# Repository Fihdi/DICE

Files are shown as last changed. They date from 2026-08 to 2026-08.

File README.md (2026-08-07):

# 6hp Sample and Hold / Random voltage generator

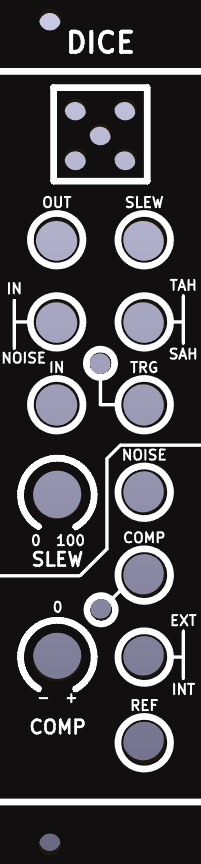
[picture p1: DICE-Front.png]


DICE contains a white noise generator, sample and hold and a comparator. This 6hp module creates various random voltages and gates, bringing variety and unpredictability into your patches. 

# Applications

- Random voltage generator
- Random gate generator
- Slew rate limiter
- Track and hold
- White noise generator
- Burst generator

# Jumpers
Two jumpers on the back of the module allow the COMP output to be configured:
- **Jumper in the ON position:** A trigger from TRG is always routed to the COMP output. This ensures an on-time trigger when using the COMP output as a burst generator.
- **Jumper in the OFF position**: The trigger from TRG is not routed to the COMP output.
- **Jumper in the AND position:** The COMP output is only active while a gate signal is present at the TRG input.
- **Jumper not in the AND position:** COMP outputs HIGH or LOW signals regardless of the TRG input.

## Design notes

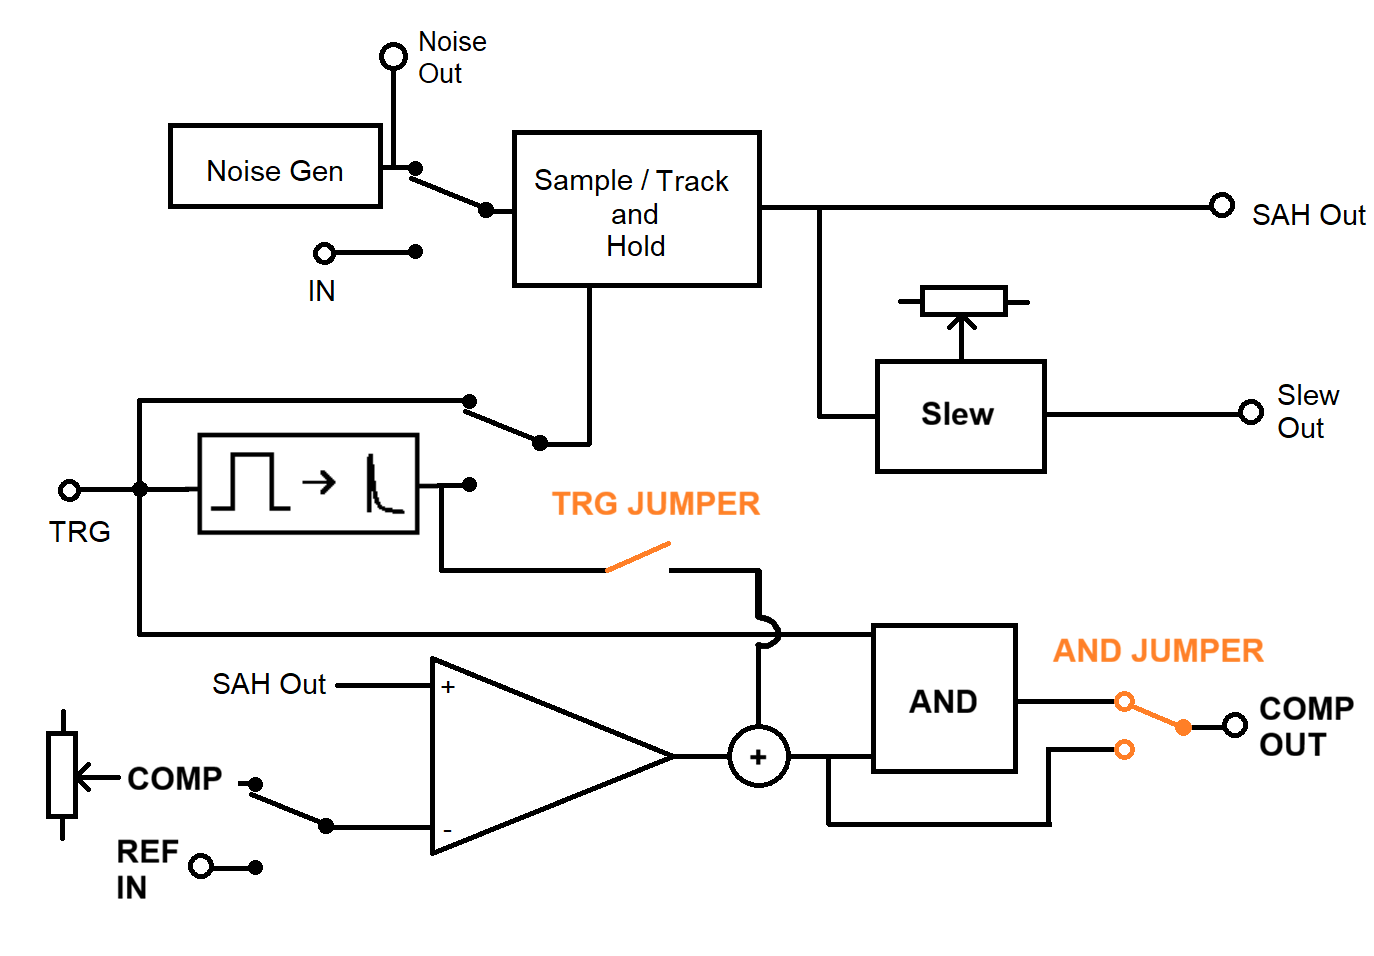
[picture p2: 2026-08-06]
DICE-BLOCK.png

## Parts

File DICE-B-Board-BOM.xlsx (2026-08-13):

 |  |  | DICE B-Board BOM
Item # | *Designator | *Qty | Manufacturer | *Mfg Part # | Description / Value | *Package/Footprint | Type | Your Instructions / Notes
1 | C1,C105,C106 | 3 |  | C309030 | 100n | Capacitor_SMD:C_1206_3216Metric
2 | C2 | 1 |  |  | 10p | Capacitor_SMD:C_1206_3216Metric |  | DNP
3 | C3,C104 | 2 |  | C377070 | 1u | Capacitor_SMD:C_1206_3216Metric
4 | C101,C103 | 2 |  | C5137623 | 10n | Capacitor_SMD:C_1206_3216Metric
5 | C102 | 1 |  | C282811 | 1n | Capacitor_SMD:C_1206_3216Metric
6 | D101,D102,D103,D104,D110,D111,D112,D113,D114,D117 | 10 |  | C917117 | 1N4148 | Diode_SMD:D_SOD-323_HandSoldering
7 | J2,J101,J109,J116 | 4 |  |  | Conn_01x03_Pin | Connector_PinHeader_2.54mm:PinHeader_1x03_P2.54mm_Vertical |  | DNP
8 | J110 | 1 |  |  | Conn_01x05_Pin | Connector_PinHeader_2.54mm:PinHeader_1x05_P2.54mm_Vertical |  | DNP
9 | J114,J115 | 2 |  |  | Conn_01x07_Pin | Connector_PinHeader_2.54mm:PinHeader_1x07_P2.54mm_Vertical |  | DNP
10 | Q101,Q102,Q103 | 3 |  | C475630 | BC847 | Package_TO_SOT_SMD:SOT-23
11 | R1,R134 | 2 |  | C2907373 | 1M | Resistor_SMD:R_1206_3216Metric
12 | R2 | 1 |  | C2090939 | 2M2 | Resistor_SMD:R_1206_3216Metric
13 | R4,R127,R128,R129,R130,R131 | 6 |  | C2907387 | 4k7 | Resistor_SMD:R_1206_3216Metric
14 | R5,R6,R13,R101,R102,R103,R104,R105,R106,R107,R108,R110,R111,R112,R114 | 15 |  | C2907421 | 100k | Resistor_SMD:R_1206_3216Metric
15 | R7,R113,R116 | 3 |  | C131398 | 1k | Resistor_SMD:R_1206_3216Metric
16 | R109,R123,R124,R125,R126 | 5 |  | C2907423 | 10k | Resistor_SMD:R_1206_3216Metric
17 | R119 | 1 |  | C2907507 | 47k | Resistor_SMD:R_1206_3216Metric
18 | R121,R122 | 2 |  | C2907483 | 33k | Resistor_SMD:R_1206_3216Metric
19 | U1,U102,U103 | 3 |  | C12594 | TL074 | Package_SO:SOIC-14_3.9x8.7mm_P1.27mm
20 | U101 | 1 |  | C6601631 | DG412xUE | Package_SO:TSSOP-16_4.4x5mm_P0.65mm

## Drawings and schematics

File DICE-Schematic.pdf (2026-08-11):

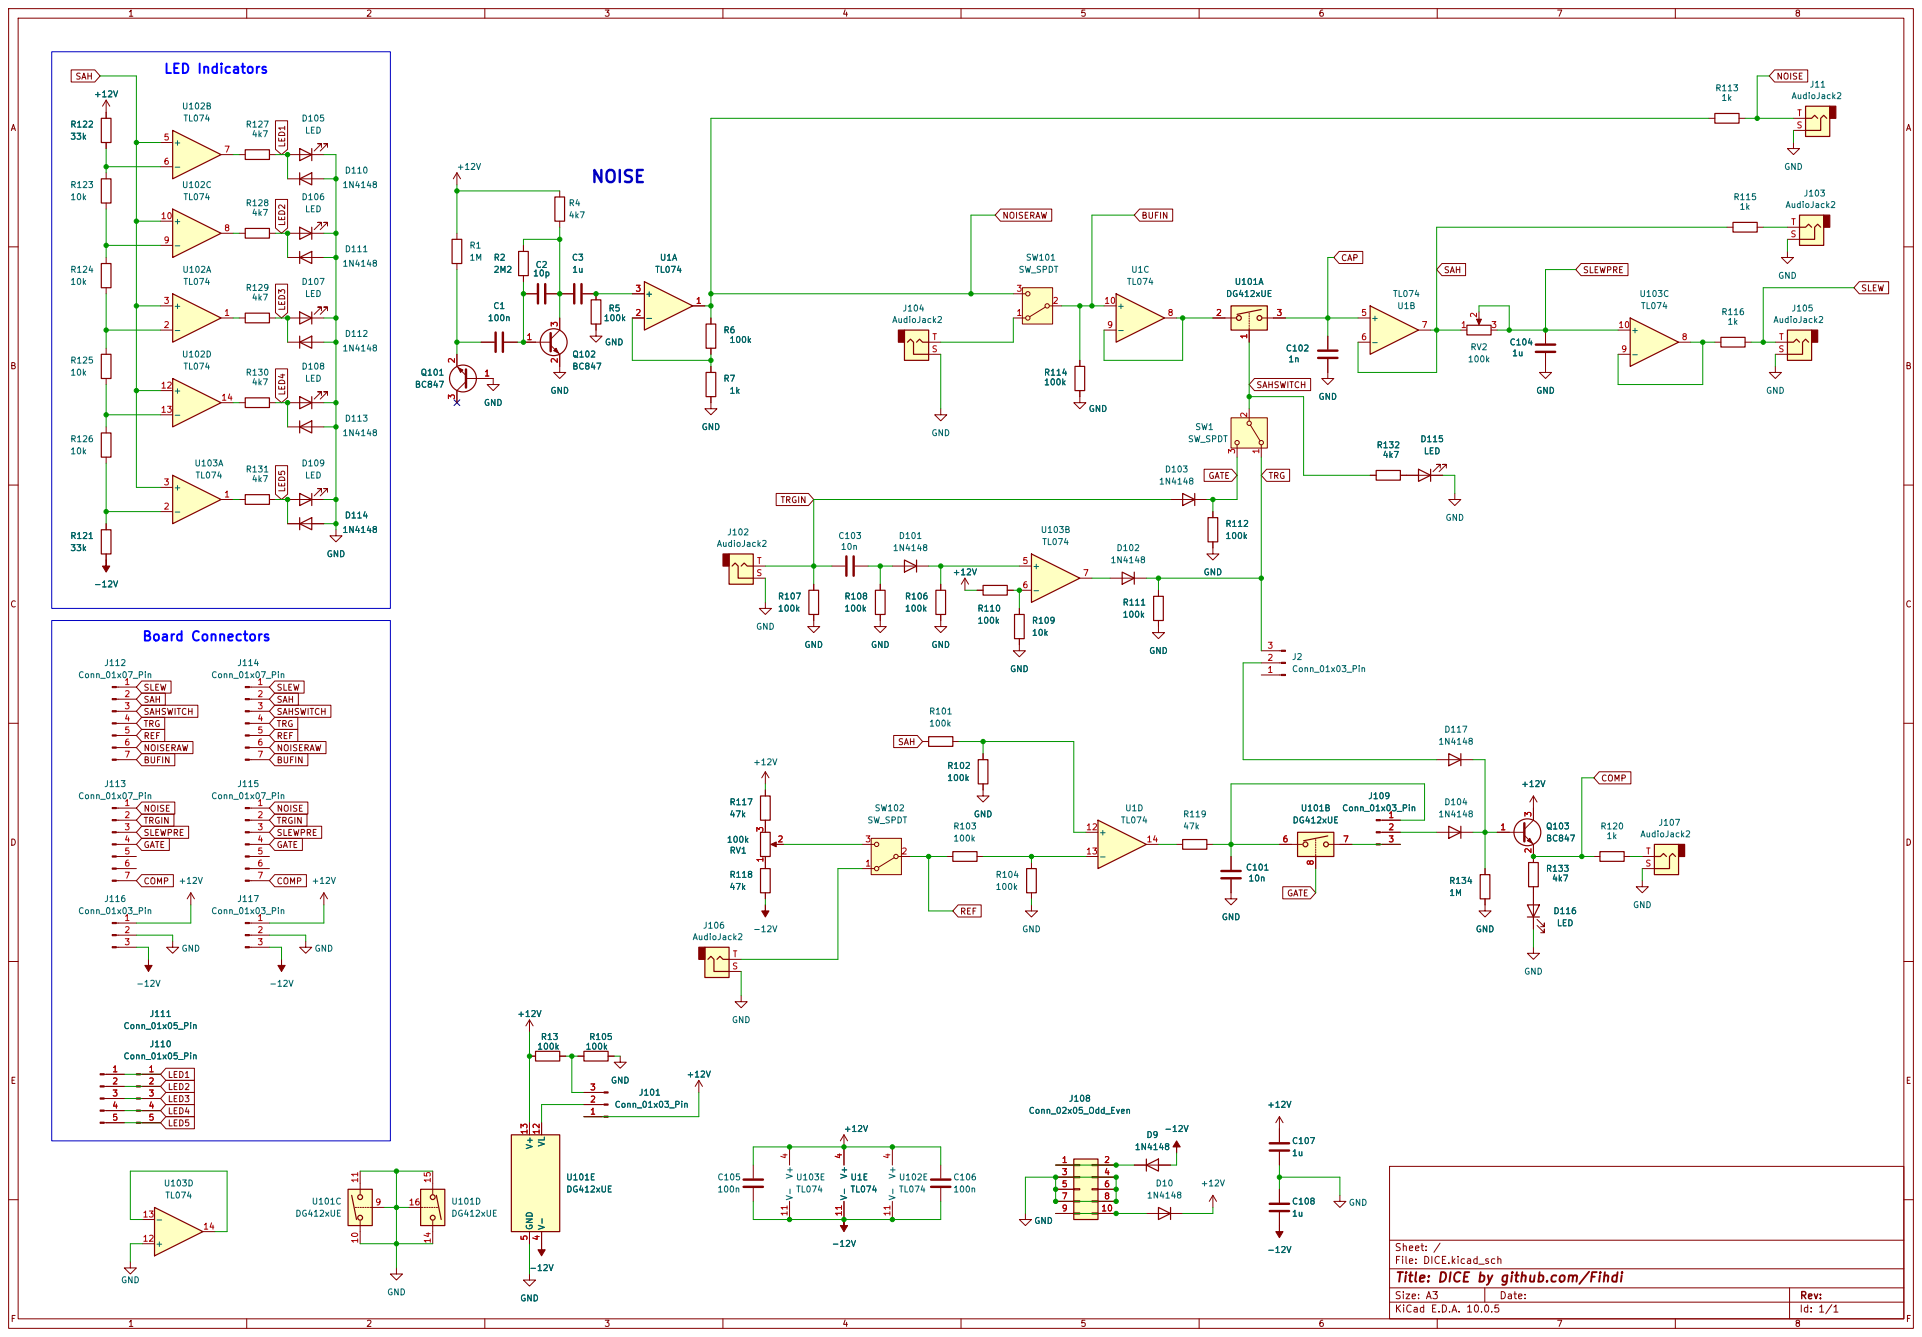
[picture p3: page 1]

Sheet: /
File: DICE.kicad_sch
Title: DICE by github.com/Fihdi

Size: A3 | Rev: | F Date:
KiCad E.D.A. 10.0.5 | Id: 1/1

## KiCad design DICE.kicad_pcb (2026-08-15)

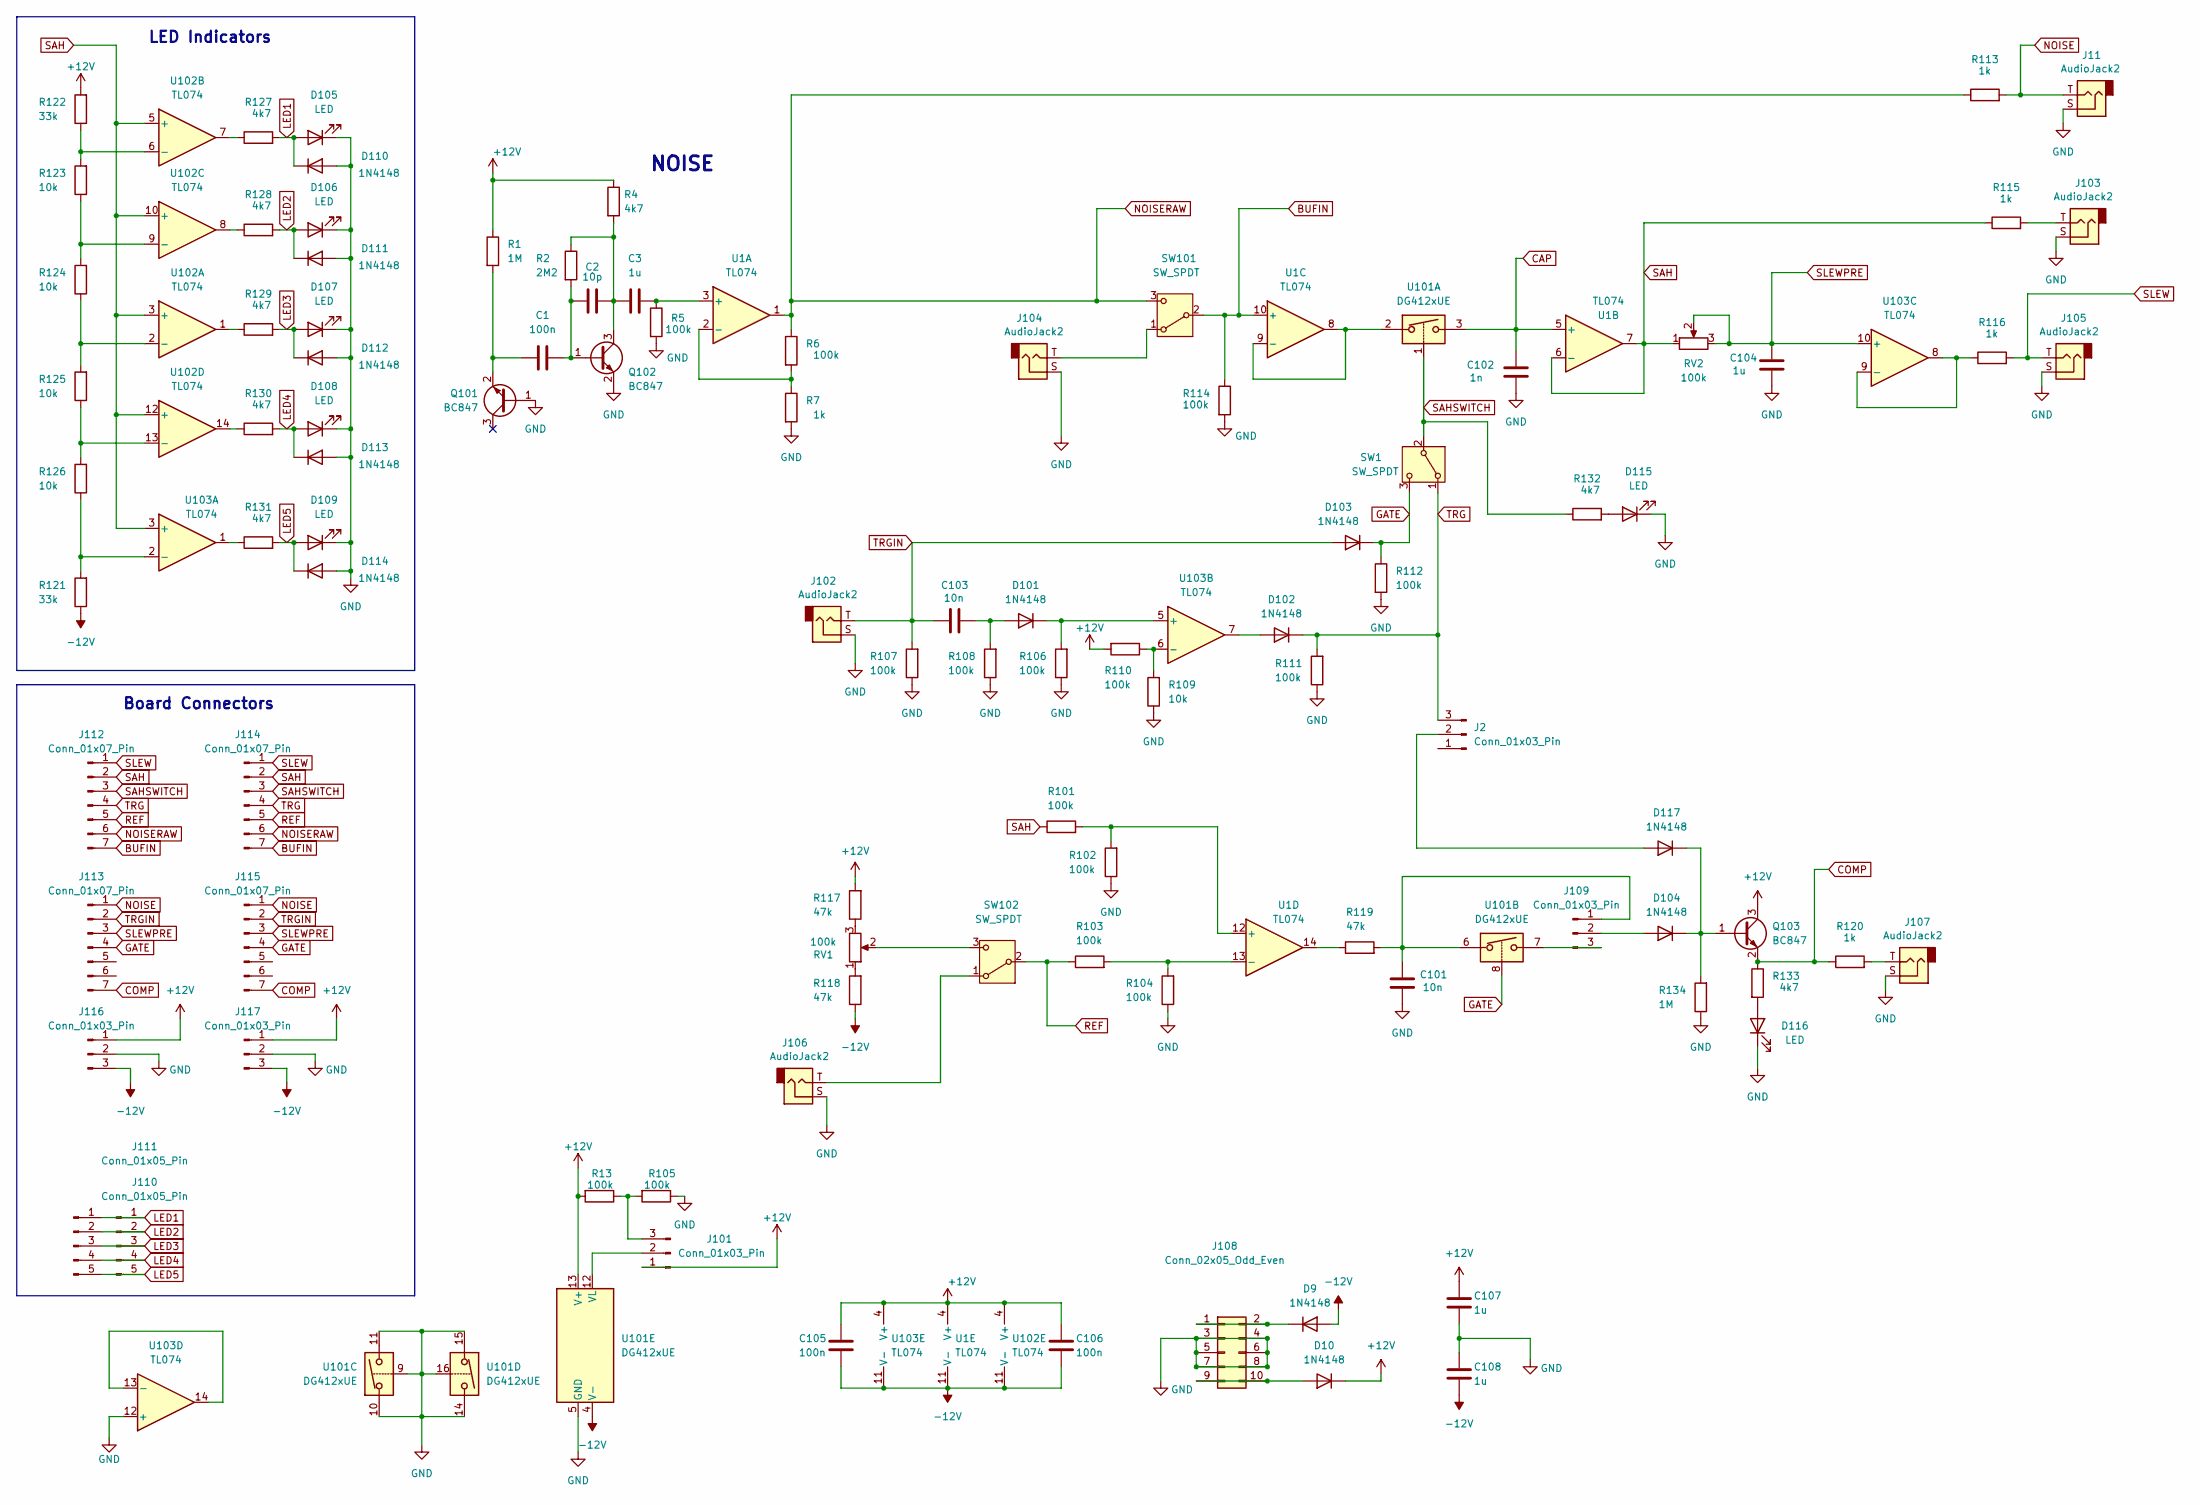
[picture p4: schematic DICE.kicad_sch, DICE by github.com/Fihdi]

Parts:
C1, C105, C106: 100n; C_1206_3216Metric
C2: 10p; C_1206_3216Metric
C3, C104, C107, C108: 1u; C_1206_3216Metric
C101, C103: 10n; C_1206_3216Metric
C102: 1n; C_1206_3216Metric
D9, D10, D101, D102, D103, D104, D110, D111, D112, D113, D114, D117: 1N4148; D_SOD-323_HandSoldering
D105, D106, D107, D108, D109, D115, D116: LED; LED_D3.0mm
J2, J101, J109, J116, J117: Conn_01x03_Pin; PinHeader_1x03_P2.54mm_Vertical
J11, J102, J103, J104, J105, J106, J107: AudioJack2; MonoTRS
J108: Conn_02x05_Odd_Even; IDC-Header_2x05_P2.54mm_Vertical
J110, J111: Conn_01x05_Pin; PinHeader_1x05_P2.54mm_Vertical
J112, J113, J114, J115: Conn_01x07_Pin; PinHeader_1x07_P2.54mm_Vertical
Q101, Q102, Q103: BC847; SOT-23
R1, R134: 1M; R_1206_3216Metric
R2: 2M2; R_1206_3216Metric
R4, R127, R128, R129, R130, R131, R132, R133: 4k7; R_1206_3216Metric
R5, R6, R13, R101, R102, R103, R104, R105, R106, R107, R108, R110, R111, R112, R114: 100k; R_1206_3216Metric
R7, R113, R115, R116, R120: 1k; R_1206_3216Metric
R109, R123, R124, R125, R126: 10k; R_1206_3216Metric
R117, R118, R119: 47k; R_1206_3216Metric
R121, R122: 33k; R_1206_3216Metric
RV1, RV2: 100k; Potentiometer_Alpha_RD901F-40-00D_Single_Vertical
SW1, SW101, SW102: SW_SPDT; Switch
U1, U102, U103: TL074; SOIC-14_3.9x8.7mm_P1.27mm
U101: DG412xUE; TSSOP-16_4.4x5mm_P0.65mm

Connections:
+12V: C105.1, C106.2, C107.2, D10.1 (K), J101.1, J116.1, J117.1, Q103.3 (C), R1.1, R4.1, R13.2, R110.2, R117.2, R122.2, U1.4 (V+), U101.13 (V+), U102.4 (V+), U103.4 (V+)
-12V: C105.2, C106.1, C108.1, D9.2 (A), J116.3, J117.3, R118.1, R121.1, U1.11 (V-), U101.4 (V-), U102.11 (V-), U103.11 (V-)
BUFIN: J112.7, J114.7, R114.1, SW101.2 (B), U1.10 (+)
CAP: C102.2, U1.5 (+), U101.3
COMP: J113.7, J115.7, Q103.2 (E), R120.1, R133.1
GATE: D103.1 (K), J113.4, J115.4, R112.1, SW1.3 (C), U101.8
GND: C101.1, C102.1, C104.1, C107.1, C108.2, D105.1 (K), D106.1 (K), D107.1 (K), D108.1 (K), D109.1 (K), D110.2 (A), D111.2 (A), D112.2 (A), D113.2 (A), D114.2 (A), D115.1 (K), D116.1 (K), J11.S, J102.S, J103.S, J104.S, J105.S, J106.S, J107.S, J108.3, J108.4, J108.5, J108.6, J108.7, J108.8, J116.2, J117.2, Q101.1 (B), Q102.2 (E), R5.2, R7.2, R102.1, R104.1, R105.1, R106.1, R107.1, R108.1, R109.1, R111.1, R112.2, R114.2, R134.1, U101.5 (GND), U101.9, U101.10, U101.11, U101.14, U101.15, U101.16, U103.12 (+)
LED1: D105.2 (A), D110.1 (K), J110.1, J111.1, R127.2
LED2: D106.2 (A), D111.1 (K), J110.2, J111.2, R128.2
LED3: D107.2 (A), D112.1 (K), J110.3, J111.3, R129.2
LED4: D108.2 (A), D113.1 (K), J110.4, J111.4, R130.2
LED5: D109.2 (A), D114.1 (K), J110.5, J111.5, R131.2
NOISE: J11.T, J113.1, J115.1, R113.2
NOISERAW: J112.6, J114.6, R6.1, R113.1, SW101.3 (C), U1.1
unnamed: D9.1 (K), J108.1, J108.2
unnamed: D10.2 (A), J108.9, J108.10
unnamed: C103.2, D101.2 (A), R108.2
unnamed: D101.1 (K), R106.2, U103.5 (+)
unnamed: D102.2 (A), U103.7
unnamed: D104.2 (A), J109.2
unnamed: D104.1 (K), D117.1 (K), Q103.1 (B), R134.2
unnamed: D115.2 (A), R132.2
unnamed: D116.2 (A), R133.2
unnamed: D117.2 (A), J2.2
unnamed: J101.2, U101.12 (VL)
unnamed: J101.3, R13.1, R105.2
unnamed: J103.T, R115.2
unnamed: J107.T, R120.2
unnamed: C101.2, J109.1, R119.2, U101.6
unnamed: J109.3, U101.7
unnamed: C1.1, Q101.2 (E), R1.2
unnamed: C1.2, C2.1, Q102.1 (B), R2.2
unnamed: C2.2, C3.1, Q102.3 (C), R2.1, R4.2
unnamed: R117.1, RV1.3
unnamed: R118.2, RV1.1
unnamed: R119.1, U1.14
unnamed: R127.1, U102.7
unnamed: R128.1, U102.8
unnamed: R129.1, U102.1
unnamed: R130.1, U102.14
unnamed: R131.1, U103.1
unnamed: J104.T, SW101.1 (A)
unnamed: J106.T, SW102.1 (A)
unnamed: RV1.2, SW102.3 (C)
unnamed: C3.2, R5.1, U1.3 (+)
unnamed: R6.2, R7.1, U1.2 (-)
unnamed: U1.8, U1.9 (-), U101.2
unnamed: R101.2, R102.2, U1.12 (+)
unnamed: R103.2, R104.2, U1.13 (-)
unnamed: R124.1, R125.2, U102.2 (-)
unnamed: R122.1, R123.2, U102.6 (-)
unnamed: R123.1, R124.2, U102.9 (-)
unnamed: R125.1, R126.2, U102.13 (-)
unnamed: R121.2, R126.1, U103.2 (-)
unnamed: R109.2, R110.1, U103.6 (-)
unnamed: R116.1, U103.8, U103.9 (-)
unnamed: U103.13 (-), U103.14
REF: J112.5, J114.5, R103.1, SW102.2 (B)
SAH: J112.2, J114.2, R101.1, R115.1, RV2.1, U1.6 (-), U1.7, U102.3 (+), U102.5 (+), U102.10 (+), U102.12 (+), U103.3 (+)
SAHSWITCH: J112.3, J114.3, R132.1, SW1.2 (B), U101.1
SLEW: J105.T, J112.1, J114.1, R116.2
SLEWPRE: C104.2, J113.3, J115.3, RV2.2, RV2.3, U103.10 (+)
TRG: D102.1 (K), J2.3, J112.4, J114.4, R111.2, SW1.1 (A)
TRGIN: C103.1, D103.2 (A), J102.T, J113.2, J115.2, R107.2

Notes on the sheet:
NOISE
LED Indicators
Board Connectors

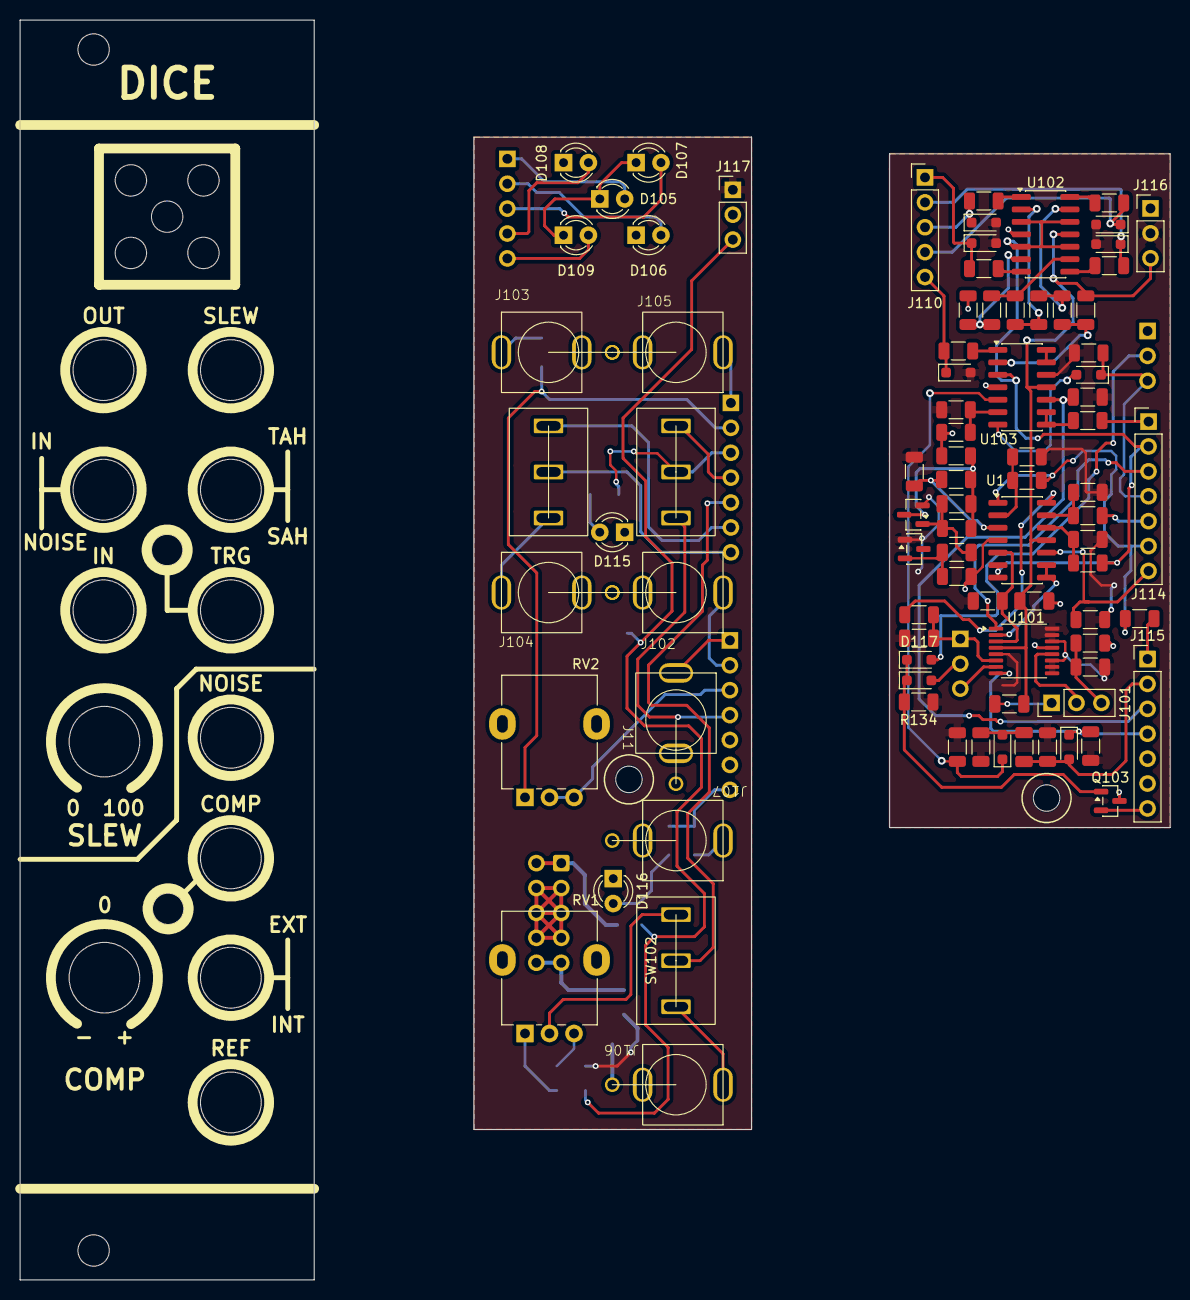
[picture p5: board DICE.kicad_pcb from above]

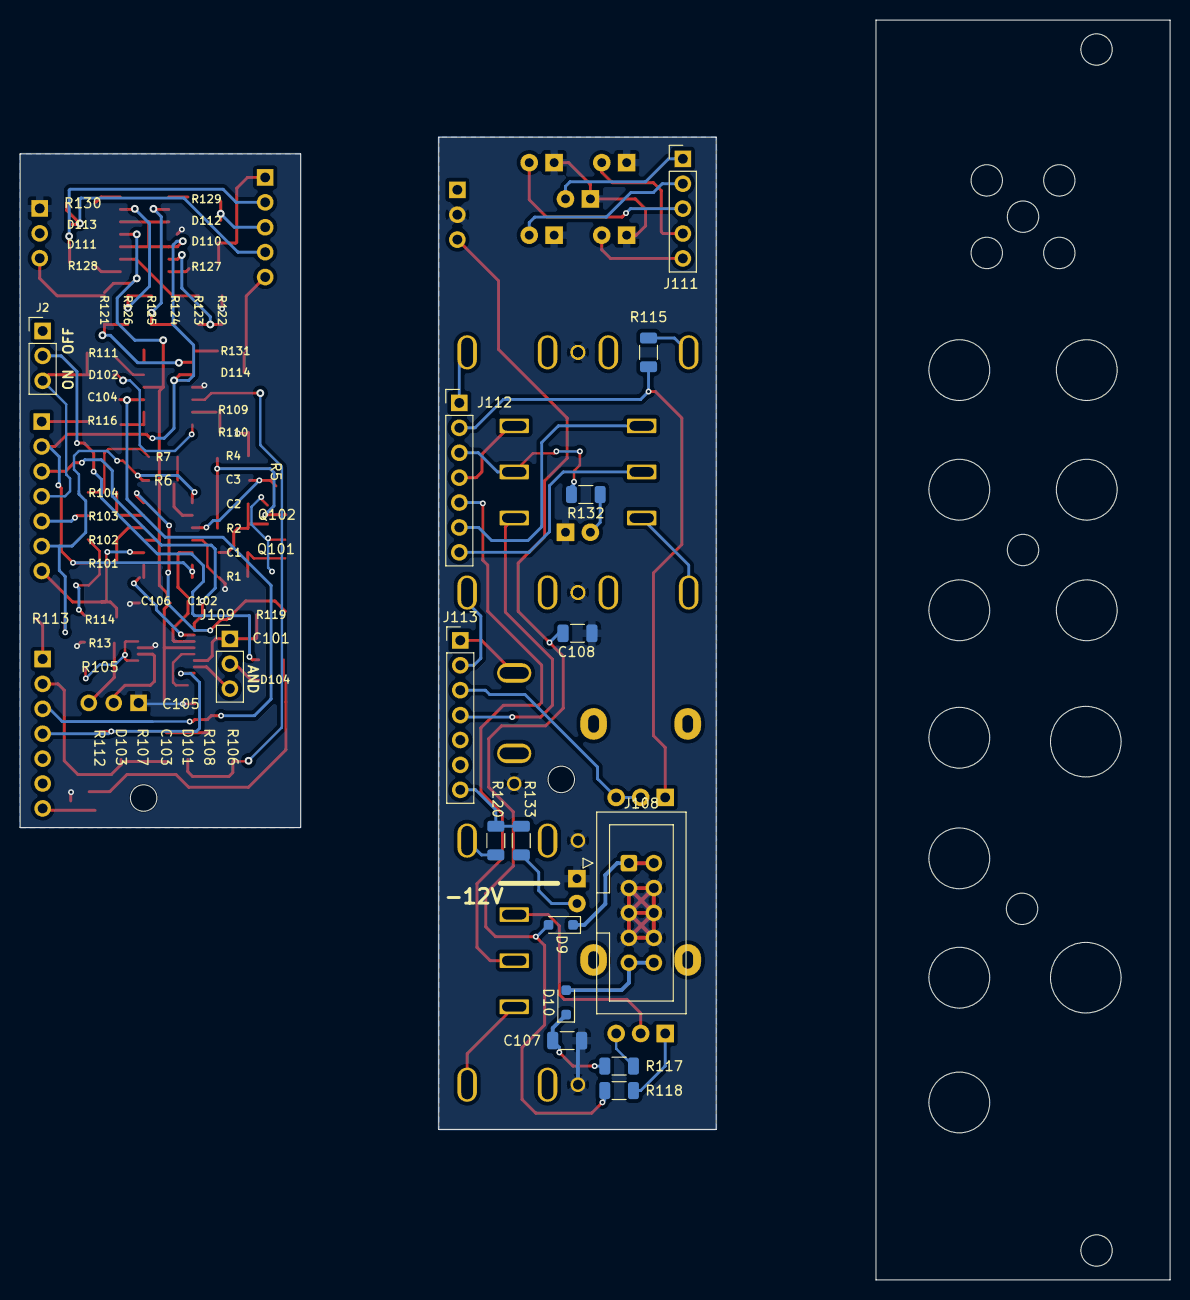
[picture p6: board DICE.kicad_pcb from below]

Board: 2 copper layers, 117.3 x 128.5 mm, 102 parts (16 on the bottom side), 64 nets.

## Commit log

2026-08-06 Added Silkscreen Info for the Jumpers
    [DICE.kicad_pcb]
2026-08-07 Added TRG LED
    [DICE.kicad_pcb, DICE.kicad_sch]
2026-08-07 Added an LED indicator to the COMP output
    [DICE.kicad_pcb, DICE.kicad_sch]
2026-08-11 Fixed false positive triggers on COMP output
    [DICE-B-Board-BOM.csv, DICE-B-Board-BOM.xlsx, DICE.kicad_pcb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]
2026-08-12 Duplicate item removed
    [DICE-B-Board-BOM.xlsx]
